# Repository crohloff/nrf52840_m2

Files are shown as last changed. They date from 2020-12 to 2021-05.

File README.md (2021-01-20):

# nrf52840_m2
nrf52840 based M.2 b-key module

## dimensions
- 22mm x 30mm

## features
- m.2 2230 b-key form factor board
- dedicated smd chip antenna for bt
- U.fl connector for NFC antenna
- TC2030 debug connector
- RGB led
- power path management (USB or battery connected)
- battery charging circuit 500mA charging current
- up to 24 free programmable GPIOs(4 analog) without expensive uVias

## board front
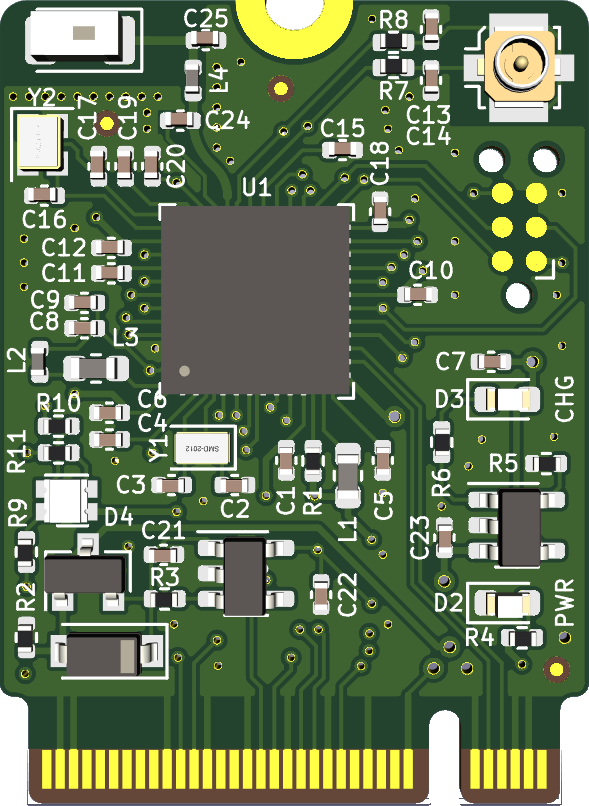
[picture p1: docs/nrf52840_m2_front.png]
board front


## board back
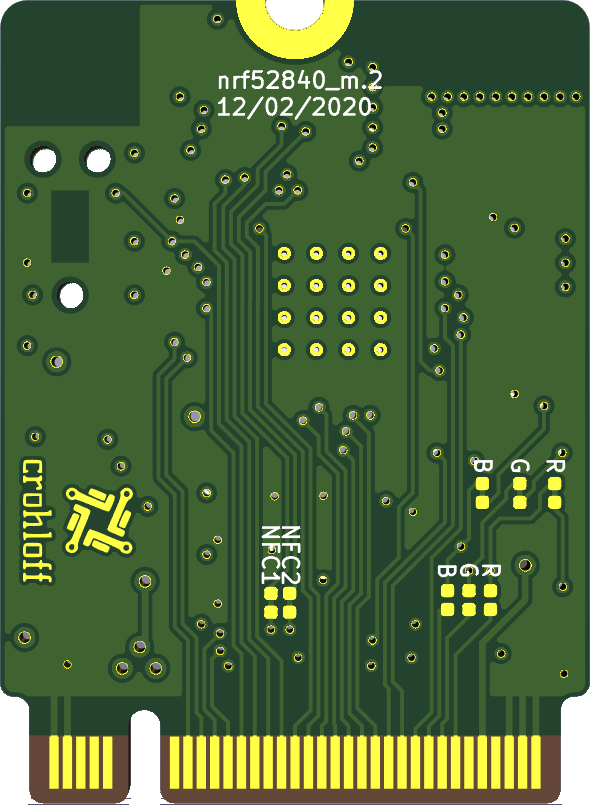
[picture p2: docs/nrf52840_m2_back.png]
board back


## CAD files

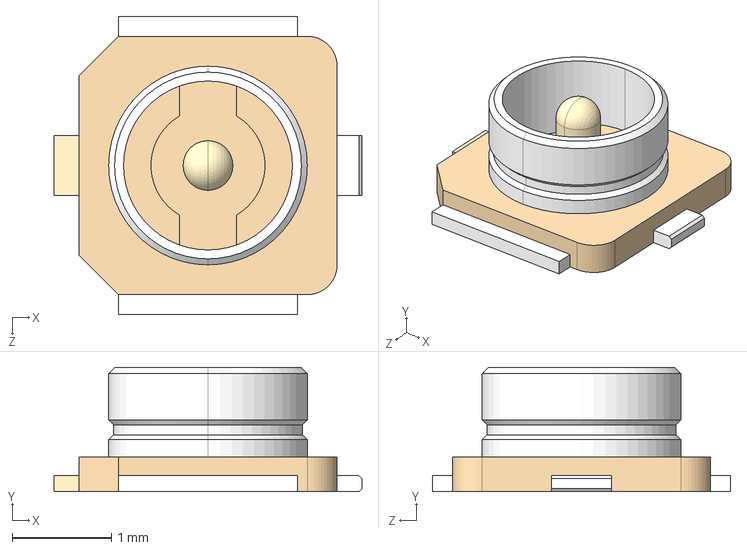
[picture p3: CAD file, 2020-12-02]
custom_3d/A-1JB--3DModel-STEP-56544.STEP
3.10 x 1.25 x 3.00 mm

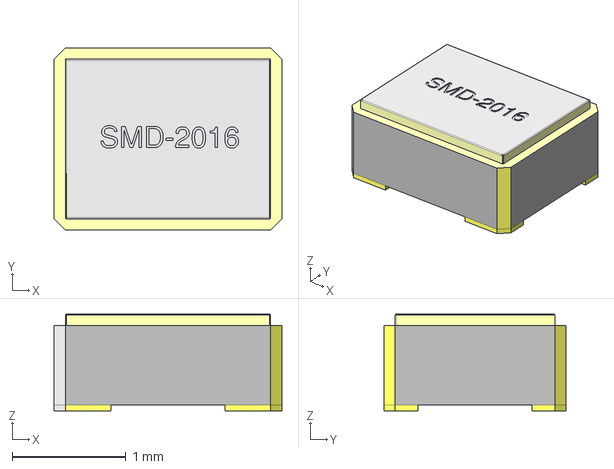
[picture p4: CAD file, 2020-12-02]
custom_3d/Crystal_SMD_2016-4Pin_2.0x1.6mm.stp
2.00 x 1.60 x 0.85 mm

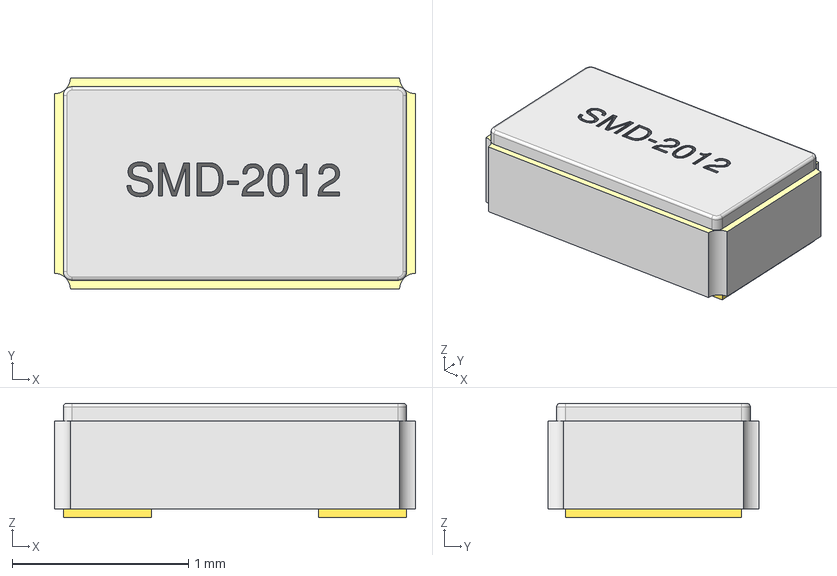
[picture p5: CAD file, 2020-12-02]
custom_3d/Crystal_SMD_2012-2Pin_2.0x1.2mm.stp
2.05 x 1.20 x 0.65 mm

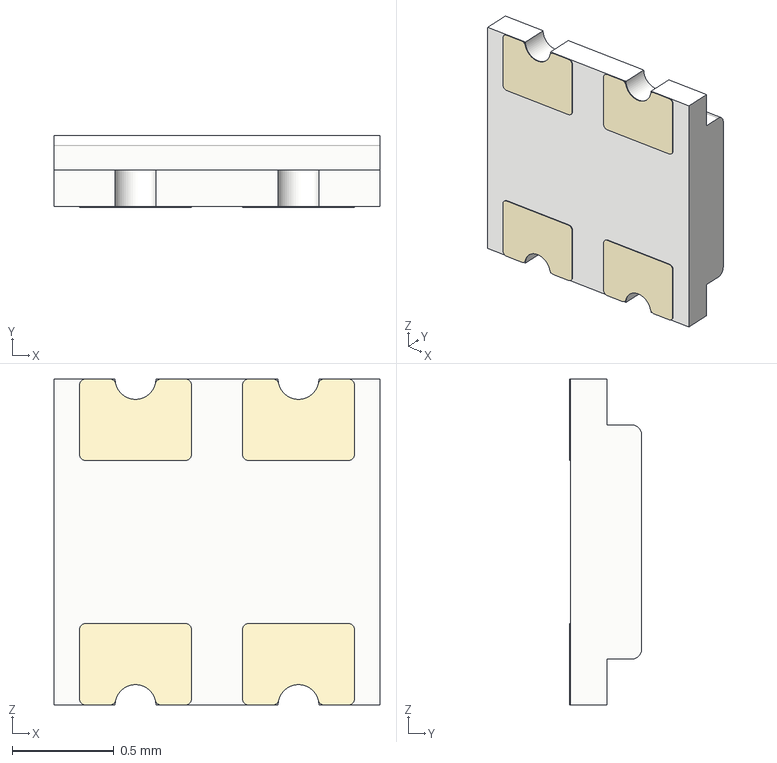
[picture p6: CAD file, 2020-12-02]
custom_3d/RGB LED - LTST-C19HE1WT.step
1.60 x 0.355 x 1.60 mm

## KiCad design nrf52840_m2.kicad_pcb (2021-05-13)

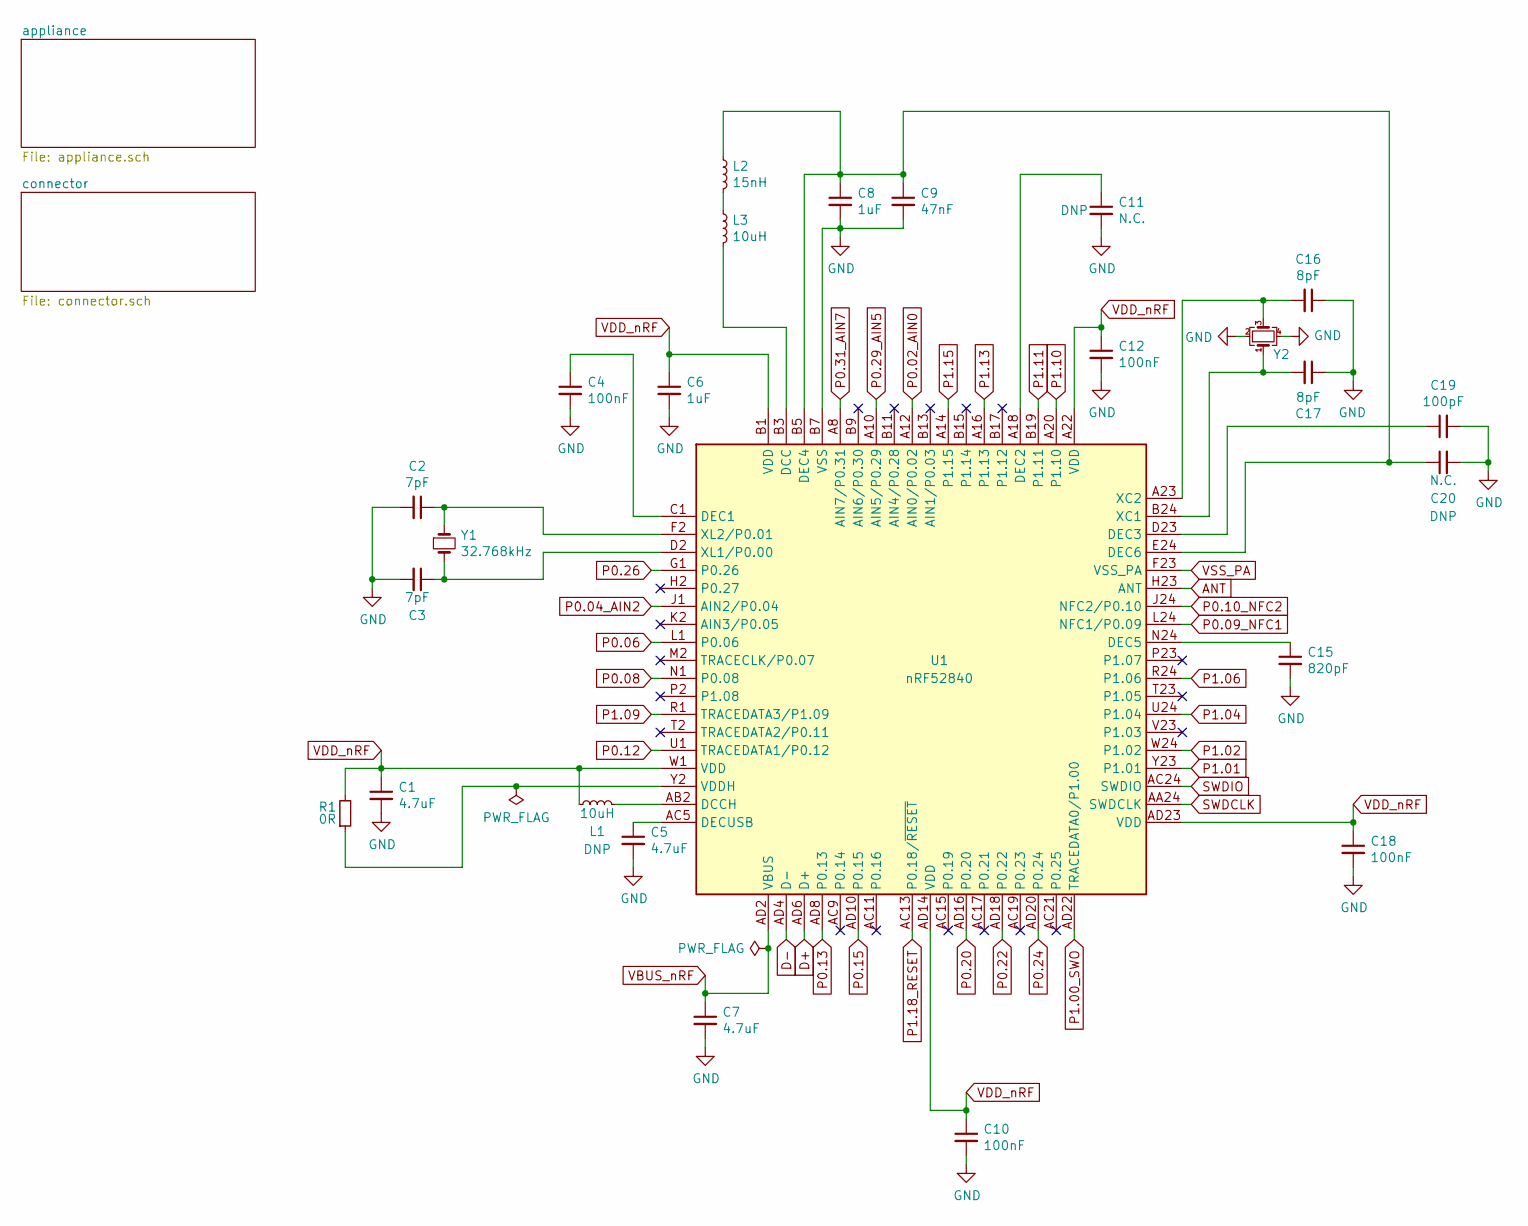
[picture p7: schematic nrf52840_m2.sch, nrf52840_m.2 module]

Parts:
C1, C5, C7: 4.7uF; C_0402_1005Metric; MFG P/N JMK105BBJ475MV-F; Digikey 587-2787-1-ND
C2, C3: 7pF; C_0402_1005Metric; MFG P/N GRM1555C1H7R0BA01D; Digikey 490-6254-1-ND
C4, C10, C12, C18: 100nF; C_0402_1005Metric; MFG P/N CL05A104KP5NNNC; Digikey 1276-1022-1-ND
C6, C8: 1uF; C_0402_1005Metric; MFG P/N CL05A105KO5NNNC; Digikey 1276-1067-1-ND
C9: 47nF; C_0402_1005Metric; MFG P/N CC0402KRX7R9BB473; Digikey 311-3815-1-ND
C11, C20: N.C.; C_0402_1005Metric
C15: 820pF; C_0402_1005Metric; MFG P/N CL05B821KB5NNNC; Digikey 1276-1589-1-ND
C16, C17: 8pF; C_0402_1005Metric; MFG P/N CC0402CRNPO9BN8R0; Digikey 311-3328-1-ND
C19: 100pF; C_0402_1005Metric; MFG P/N CC0402JRNPO9BN101; Digikey 311-1024-1-ND
L1, L3: 10uH; L_0603_1608Metric; MFG P/N LQM18FN100M00D; Digikey 490-4025-1-ND
L2: 15nH; L_0402_1005Metric; MFG P/N LQW15AN15NG00D; Digikey 490-6771-1-ND
R1: 0R; R_0402_1005Metric; MFG P/N RC0402JR-070RL; Digikey 311-0.0JRCT-ND
U1: nRF52840; Nordic_AQFN-73-1EP_7x7mm_P0.5mm; MFG P/N NRF52840-QIAA-R; Digikey 1490-1071-1-ND
Y1: 32.768kHz; Crystal_SMD_2012-2Pin_2.0x1.2mm; MFG P/N SC20S-7PF20PPM; Digikey 728-1076-1-ND
Y2: 32MHz; Crystal_SMD_2016-4Pin_2.0x1.6mm; MFG P/N X201632MKD4SI; LCSC C108165

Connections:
ANT: U1.H23 (ANT); also elsewhere on the board
D+: U1.AD6 (D+); also elsewhere on the board
D-: U1.AD4 (D-); also elsewhere on the board
unnamed: C2.1, U1.F2 (XL2/P0.01), Y1.1
unnamed: C3.1, U1.D2 (XL1/P0.00), Y1.2
unnamed: C4.1, U1.C1 (DEC1)
unnamed: C5.1, U1.AC5 (DECUSB)
unnamed: C11.1, U1.A18 (DEC2)
unnamed: C15.1, U1.N24 (DEC5)
unnamed: C16.2, U1.A23 (XC2), Y2.3
unnamed: C17.2, U1.B24 (XC1), Y2.1
unnamed: C19.1, U1.D23 (DEC3)
unnamed: C8.1, C9.1, C20.1, L2.1, U1.B5 (DEC4), U1.E24 (DEC6)
unnamed: L1.2, U1.AB2 (DCCH)
unnamed: L2.2, L3.1
unnamed: L3.2, U1.B3 (DCC)
unnamed: R1.1, U1.Y2 (VDDH)
P0.02_AIN0: U1.A12 (AIN0/P0.02); also elsewhere on the board
P0.04_AIN2: U1.J1 (AIN2/P0.04); also elsewhere on the board
P0.06: U1.L1 (P0.06); also elsewhere on the board
P0.08: U1.N1 (P0.08); also elsewhere on the board
P0.09_NFC1: U1.L24 (NFC1/P0.09); also elsewhere on the board
P0.10_NFC2: U1.J24 (NFC2/P0.10); also elsewhere on the board
P0.12: U1.U1 (TRACEDATA1/P0.12); also elsewhere on the board
P0.13: U1.AD8 (P0.13); also elsewhere on the board
P0.15: U1.AD10 (P0.15); also elsewhere on the board
P0.20: U1.AD16 (P0.20); also elsewhere on the board
P0.22: U1.AD18 (P0.22); also elsewhere on the board
P0.24: U1.AD20 (P0.24); also elsewhere on the board
P0.26: U1.G1 (P0.26); also elsewhere on the board
P0.29_AIN5: U1.A10 (AIN5/P0.29); also elsewhere on the board
P0.31_AIN7: U1.A8 (AIN7/P0.31); also elsewhere on the board
P1.00_SWO: U1.AD22 (TRACEDATA0/P1.00); also elsewhere on the board
P1.01: U1.Y23 (P1.01); also elsewhere on the board
P1.02: U1.W24 (P1.02); also elsewhere on the board
P1.04: U1.U24 (P1.04); also elsewhere on the board
P1.06: U1.R24 (P1.06); also elsewhere on the board
P1.09: U1.R1 (TRACEDATA3/P1.09); also elsewhere on the board
P1.10: U1.A20 (P1.10); also elsewhere on the board
P1.11: U1.B19 (P1.11); also elsewhere on the board
P1.13: U1.A16 (P1.13); also elsewhere on the board
P1.15: U1.A14 (P1.15); also elsewhere on the board
P1.18_RESET: U1.AC13 (P0.18/~RESET); also elsewhere on the board
SWDCLK: U1.AA24 (SWDCLK); also elsewhere on the board
SWDIO: U1.AC24 (SWDIO); also elsewhere on the board
VBUS_nRF: C7.1, U1.AD2 (VBUS); also elsewhere on the board
VDD_nRF: C1.1, C6.1, C10.1, C12.1, C18.1, L1.1, R1.2, U1.A22 (VDD), U1.AD14 (VDD), U1.AD23 (VDD), U1.B1 (VDD), U1.W1 (VDD); also elsewhere on the board
VSS_PA: C1.2, C2.2, C3.2, C4.2, C5.2, C6.2, C7.2, C8.2, C9.2, C10.2, C11.2, C12.2, C15.2, C16.1, C17.1, C18.2, C19.2, C20.2, U1.B7 (VSS), U1.EP (VSS), U1.F23 (VSS_PA), Y2.2, Y2.4; also elsewhere on the board

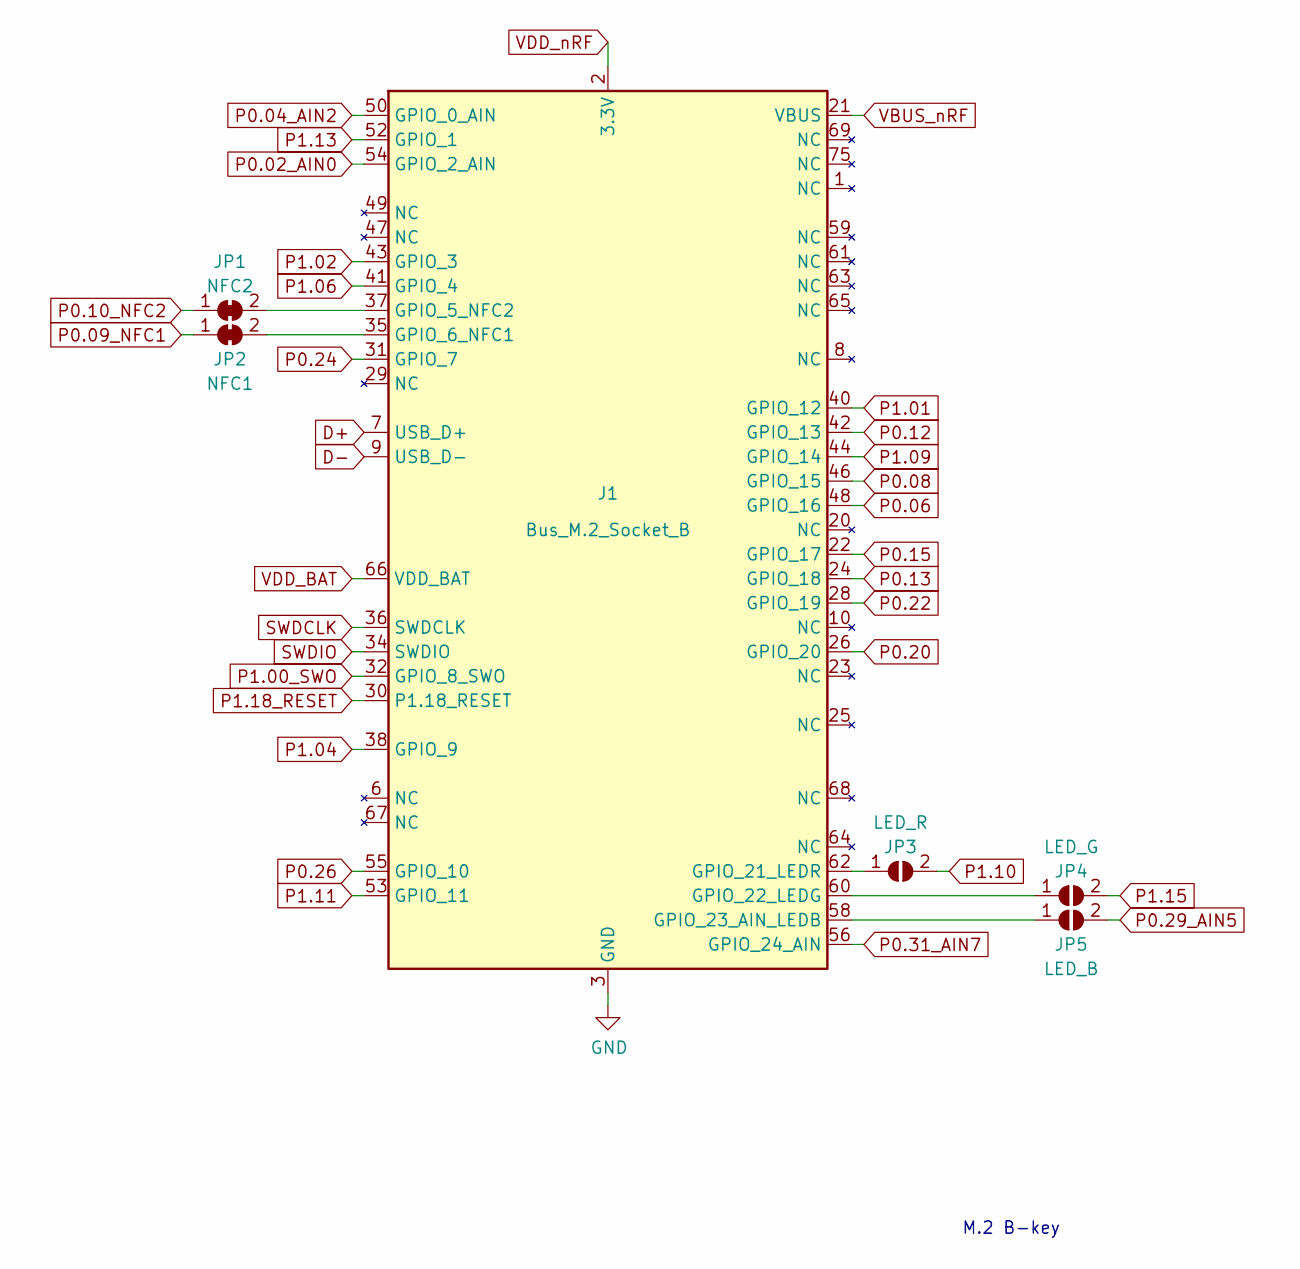
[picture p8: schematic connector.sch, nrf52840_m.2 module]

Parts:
J1: Bus_M.2_Socket_B; NGFF_B
JP1: NFC2; solder_bridge_closed
JP2: NFC1; solder_bridge_closed
JP3: LED_R; solder_bridge_open
JP4: LED_G; solder_bridge_open
JP5: LED_B; solder_bridge_open

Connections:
D+: J1.7 (USB_D+); also elsewhere on the board
D-: J1.9 (USB_D-); also elsewhere on the board
unnamed: J1.35 (GPIO_6_NFC1), JP2.2 (B)
unnamed: J1.37 (GPIO_5_NFC2), JP1.2 (B)
unnamed: J1.58 (GPIO_23_AIN_LEDB), JP5.1 (A)
unnamed: J1.60 (GPIO_22_LEDG), JP4.1 (A)
unnamed: J1.62 (GPIO_21_LEDR), JP3.1 (A)
P0.02_AIN0: J1.54 (GPIO_2_AIN); also elsewhere on the board
P0.04_AIN2: J1.50 (GPIO_0_AIN); also elsewhere on the board
P0.06: J1.48 (GPIO_16); also elsewhere on the board
P0.08: J1.46 (GPIO_15); also elsewhere on the board
P0.09_NFC1: JP2.1 (A); also elsewhere on the board
P0.10_NFC2: JP1.1 (A); also elsewhere on the board
P0.12: J1.42 (GPIO_13); also elsewhere on the board
P0.13: J1.24 (GPIO_18); also elsewhere on the board
P0.15: J1.22 (GPIO_17); also elsewhere on the board
P0.20: J1.26 (GPIO_20); also elsewhere on the board
P0.22: J1.28 (GPIO_19); also elsewhere on the board
P0.24: J1.31 (GPIO_7); also elsewhere on the board
P0.26: J1.55 (GPIO_10); also elsewhere on the board
P0.29_AIN5: JP5.2 (B); also elsewhere on the board
P0.31_AIN7: J1.56 (GPIO_24_AIN); also elsewhere on the board
P1.00_SWO: J1.32 (GPIO_8_SWO); also elsewhere on the board
P1.01: J1.40 (GPIO_12); also elsewhere on the board
P1.02: J1.43 (GPIO_3); also elsewhere on the board
P1.04: J1.38 (GPIO_9); also elsewhere on the board
P1.06: J1.41 (GPIO_4); also elsewhere on the board
P1.09: J1.44 (GPIO_14); also elsewhere on the board
P1.10: JP3.2 (B); also elsewhere on the board
P1.11: J1.53 (GPIO_11); also elsewhere on the board
P1.13: J1.52 (GPIO_1); also elsewhere on the board
P1.15: JP4.2 (B); also elsewhere on the board
P1.18_RESET: J1.30 (P1.18_RESET); also elsewhere on the board
SWDCLK: J1.36 (SWDCLK); also elsewhere on the board
SWDIO: J1.34 (SWDIO); also elsewhere on the board
VBUS_nRF: J1.21 (VBUS); also elsewhere on the board
VDD_BAT: J1.66 (VDD_BAT); also elsewhere on the board
VDD_nRF: J1.2 (3.3V), J1.4 (3.3V), J1.70 (3.3V), J1.72 (3.3V), J1.74 (3.3V); also elsewhere on the board
VSS_PA: J1.3 (GND), J1.5 (GND), J1.11 (GND), J1.27 (GND), J1.33 (GND), J1.39 (GND), J1.45 (GND), J1.51 (GND), J1.57 (GND), J1.71 (GND), J1.73 (GND); also elsewhere on the board

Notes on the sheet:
M.2 B-key

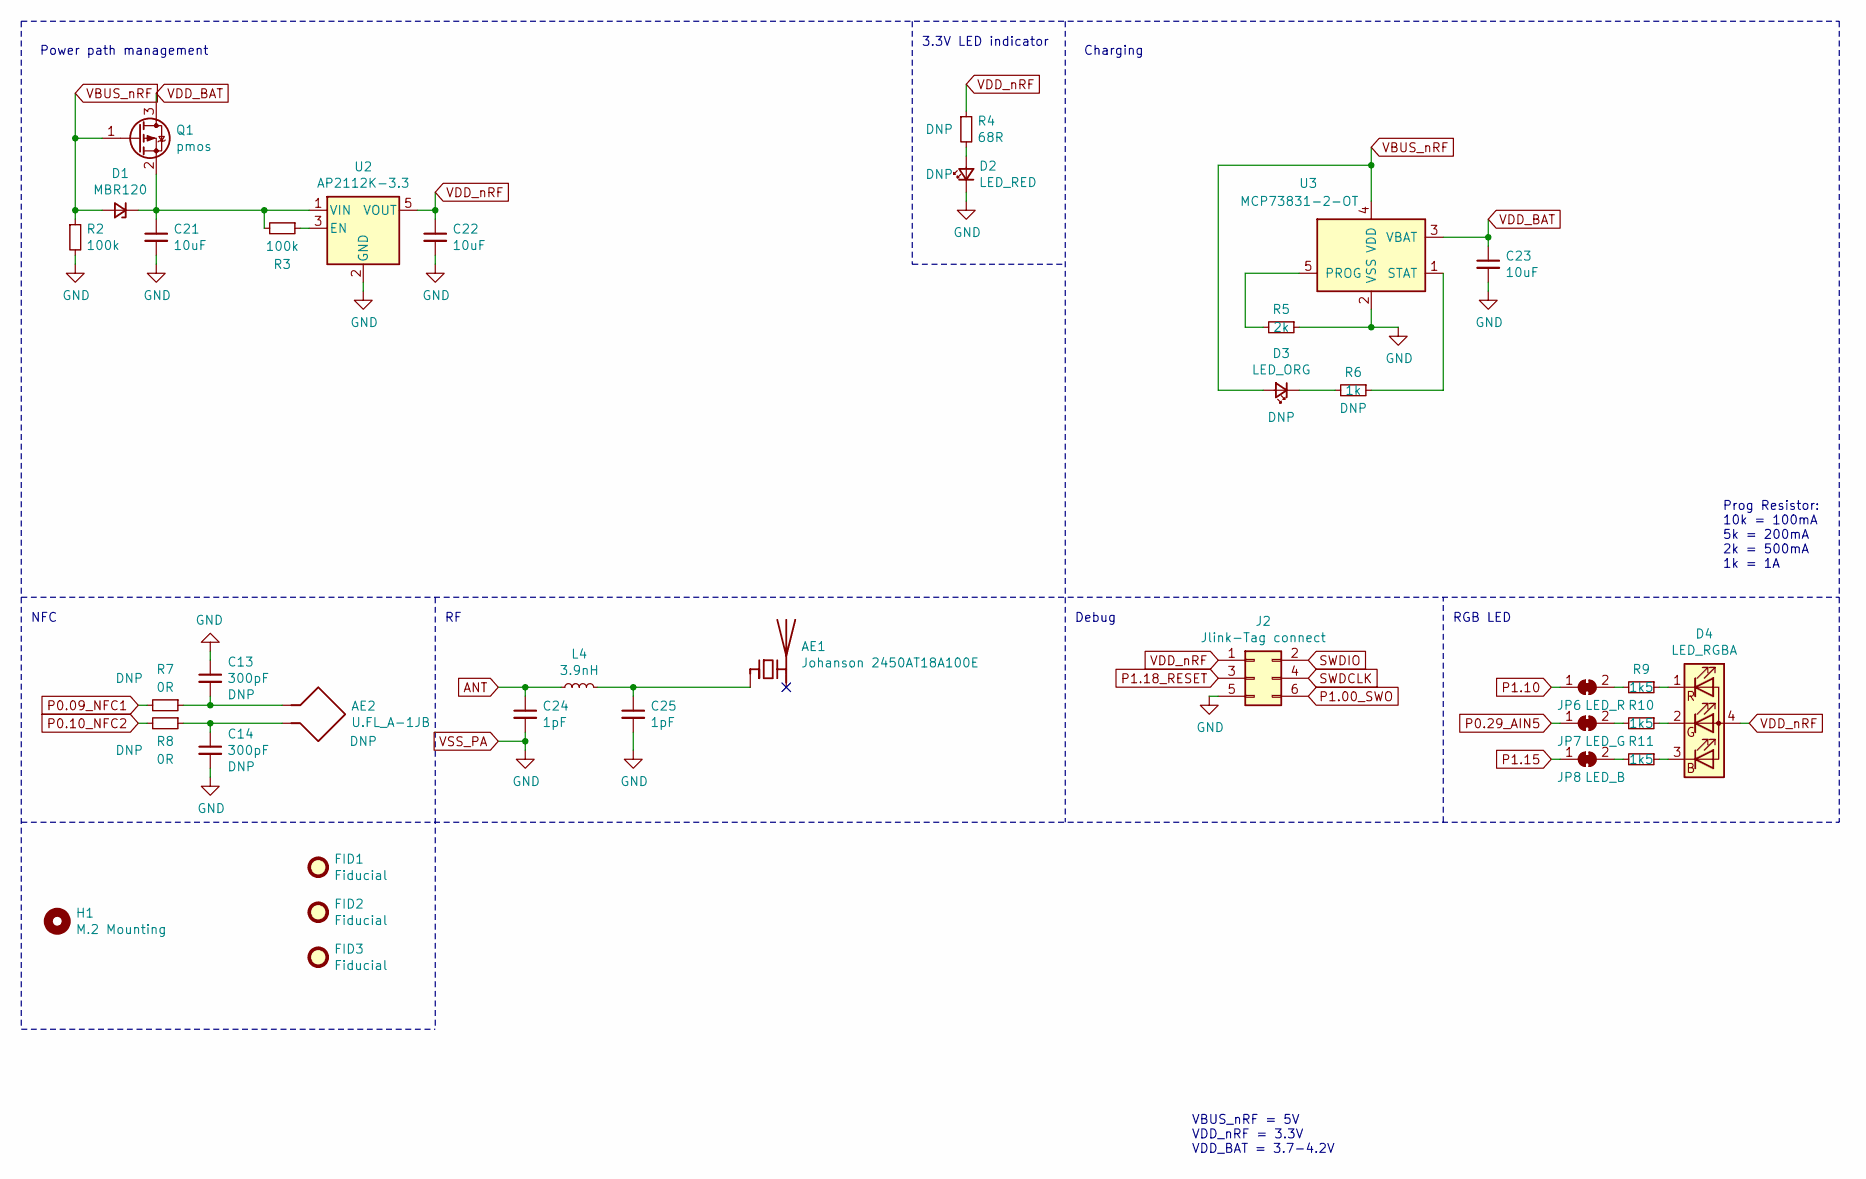
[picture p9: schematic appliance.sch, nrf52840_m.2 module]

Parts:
AE1: Johanson 2450AT18A100E; Johanson_2450AT18x100; MFG P/N 2450AT18A100E; Digikey 712-1005-1-ND
AE2: U.FL_A-1JB; CON_AMP_A-1JB; MFG P/N A-1JB; Digikey ARF1579CT-ND
C13, C14: 300pF; C_0402_1005Metric
C21, C22, C23: 10uF; C_0402_1005Metric; MFG P/N CL05A106MQ5NUNC; Digikey 1276-1451-1-ND
C24, C25: 1pF; C_0402_1005Metric; MFG P/N CC0402CRNPO9BN1R0; Digikey 311-2076-1-ND
D1: MBR120; D_SOD-123; MFG P/N MBR120VLSFT1G; Digikey MBR120VLSFT1GOSCT-ND
D2: LED_RED; LED_0603_1608Metric; MFG P/N LTST-C191KRKT; Digikey 160-1447-1-ND
D3: LED_ORG; LED_0603_1608Metric; MFG P/N LTST-C190KFKT; Digikey 160-1434-1-ND
D4: LED_RGBA; LED_LiteOn_LTST-C19HE1WT; MFG P/N LTST-C19HE1WT; Digikey 160-2162-1-ND
FID1, FID2, FID3: Fiducial; Fiducial_0.5mm_Mask1mm
H1: M.2 Mounting; MountingHole_3.2mm_M3
J2: Jlink-Tag connect; Tag-Connect_TC2030-IDC-NL_2x03_P1.27mm_Vertical
JP6: LED_R; solder_bridge_closed
JP7: LED_G; solder_bridge_closed
JP8: LED_B; solder_bridge_closed
L4: 3.9nH; L_0402_1005Metric; MFG P/N LQG15HN3N9S02D; Digikey 490-1079-1-ND
Q1: pmos; SOT-23; MFG P/N NTR1P02T1G; Digikey NTR1P02T1GOSTR-ND
R2, R3: 100k; R_0402_1005Metric; MFG P/N RC0402JR-07100KL; Digikey 311-100KJRCT-ND
R4: 68R; R_0402_1005Metric; MFG P/N AC0402FR-0768RL; Digikey YAG3507CT-ND
R5: 2k; R_0402_1005Metric; MFG P/N RC0402FR-072KL; Digikey 311-2KLRCT-ND
R6: 1k; R_0402_1005Metric; MFG P/N RC0402JR-071KL; Digikey 311-1.0KJRCT-ND
R7, R8: 0R; R_0402_1005Metric
R9, R10, R11: 1k5; R_0402_1005Metric; MFG P/N RC0402FR-071K5L; Digikey 311-1.50KLRCT-ND
U2: AP2112K-3.3; SOT-23-5; MFG P/N AP2112K-3.3TRG1; Digikey AP2112K-3.3TRG1DICT-ND
U3: MCP73831-2-OT; SOT-23-5; MFG P/N MCP73831T-2ATI/OT; Digikey MCP73831T-2ATI/OTCT-ND

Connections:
ANT: C24.1, L4.1; also elsewhere on the board
unnamed 3: AE1.1 (FEED), C25.1, L4.2; also elsewhere on the board
unnamed 5: AE2.1, C13.2, R7.1; also elsewhere on the board
unnamed 6: AE2.2, C14.1, R8.1; also elsewhere on the board
unnamed: C21.1, D1.1 (K), Q1.2 (S), R3.2, U2.1 (VIN)
unnamed: D2.2 (A), R4.2
unnamed: D3.1 (K), R6.2
unnamed: D4.1 (RK), R9.1
unnamed: D4.2 (GK), R10.1
unnamed: D4.3 (BK), R11.1
unnamed: JP6.2 (B), R9.2
unnamed: JP7.2 (B), R10.2
unnamed: JP8.2 (B), R11.2
unnamed: R3.1, U2.3 (EN)
unnamed: R5.2, U3.5 (PROG)
unnamed: R6.1, U3.1 (STAT)
P0.09_NFC1: R7.2; also elsewhere on the board
P0.10_NFC2: R8.2; also elsewhere on the board
P0.29_AIN5: JP7.1 (A); also elsewhere on the board
P1.00_SWO: J2.6; also elsewhere on the board
P1.10: JP6.1 (A); also elsewhere on the board
P1.15: JP8.1 (A); also elsewhere on the board
P1.18_RESET: J2.3; also elsewhere on the board
SWDCLK: J2.4; also elsewhere on the board
SWDIO: J2.2; also elsewhere on the board
VBUS_nRF: D1.2 (A), D3.2 (A), Q1.1 (G), R2.1, U3.4 (VDD); also elsewhere on the board
VDD_BAT: C23.1, Q1.3 (D), U3.3 (VBAT); also elsewhere on the board
VDD_nRF: C22.1, D4.4 (A), J2.1, R4.1, U2.5 (VOUT); also elsewhere on the board
VSS_PA: C13.1, C14.2, C21.2, C22.2, C23.2, C24.2, C25.2, D2.1 (K), J2.5, R2.2, R5.1, U2.2 (GND), U3.2 (VSS); also elsewhere on the board

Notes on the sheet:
VBUS_nRF = 5V VDD_nRF = 3.3V VDD_BAT = 3.7-4.2V
Power path management
Prog Resistor: 10k = 100mA 5k = 200mA 2k = 500mA 1k = 1A
Charging
NFC
Debug
3.3V LED indicator
RGB LED

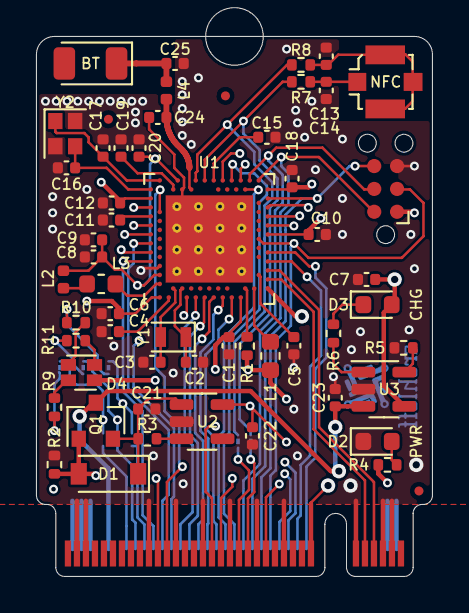
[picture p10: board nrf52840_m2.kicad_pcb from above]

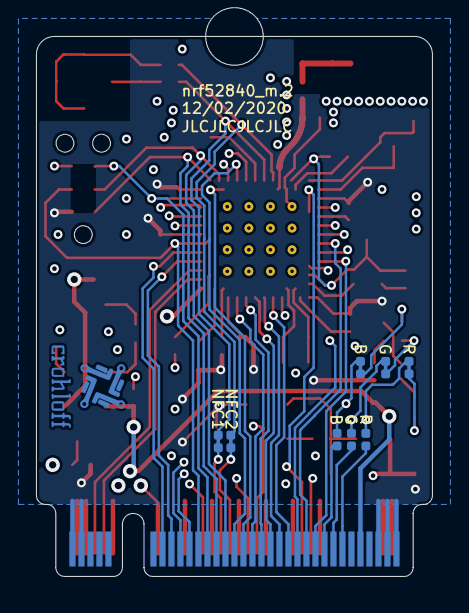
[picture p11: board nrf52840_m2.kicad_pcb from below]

Board: 4 copper layers, 22.0 x 30.0 mm, 66 parts (8 on the bottom side), 69 nets.

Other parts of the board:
BT: Johanson 2450AT18A100E; Johanson_2450AT18x100
NFC: U.FL_A-1JB; CON_AMP_A-1JB

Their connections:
unnamed 3: BT.1; also elsewhere on the board
unnamed 5: NFC.1; also elsewhere on the board
unnamed 6: NFC.2; also elsewhere on the board

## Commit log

2020-12-02 initial setup
    [A-1JB--3DModel-STEP-56544.STEP, Crystal_SMD_2012-2Pin_2.0x1.2mm.stp, Crystal_SMD_2016-4Pin_2.0x1.6mm.stp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]
2021-01-20 update 3D/docs/fiducials
    [appliance.sch, connector.sch, nrf52840_m2.kicad_pcb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]
2021-01-20 update files
    [nrf52840_m2.kicad_pcb]
2021-05-13 adjust m.2 mounting diameter
    [appliance.sch, connector.sch, nrf52840_m2.kicad_pcb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]
